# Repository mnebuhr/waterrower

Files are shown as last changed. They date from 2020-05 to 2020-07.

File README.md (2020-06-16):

# waterrower 
connect waterrower to a new Interface

Der Waterrower soll ein neues Interface bekommen. Es sollen live Daten ermittelt werden und diese auf einer grafischen interaktiven Oberfläche dargestellt werden. 

### Stand 06.06.2020 (Canvas)
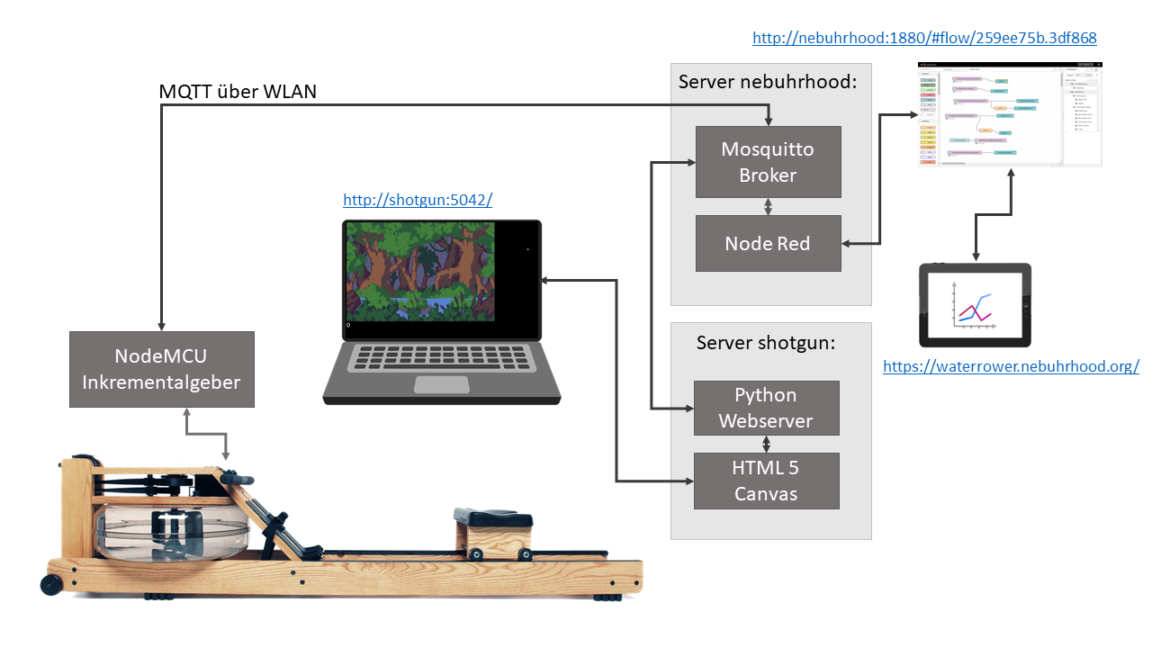
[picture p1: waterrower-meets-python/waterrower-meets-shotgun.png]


### Zwischenstand 26.05.2020 (ohne Gyrosensor)
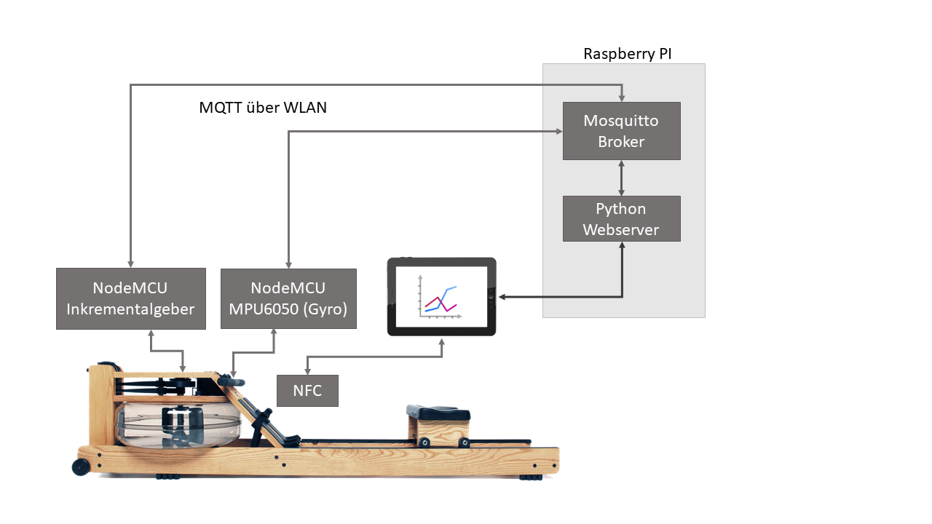
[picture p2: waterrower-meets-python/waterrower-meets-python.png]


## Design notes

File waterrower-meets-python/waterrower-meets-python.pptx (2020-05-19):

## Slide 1

Raspberry PI

Mosquitto
Broker

Python
Webserver

MQTT über WLAN

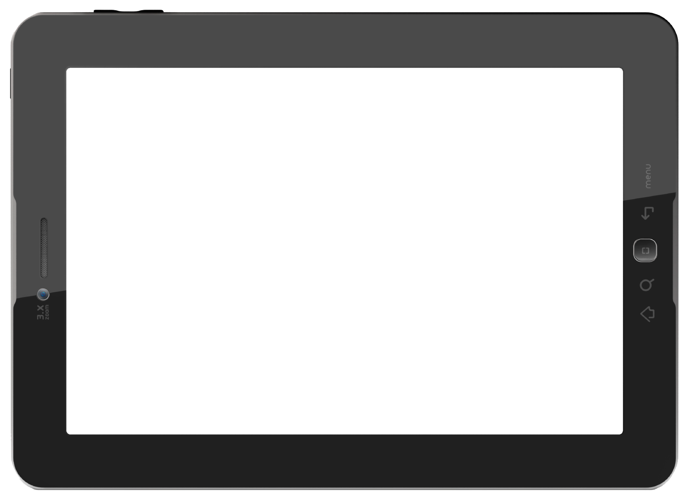
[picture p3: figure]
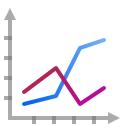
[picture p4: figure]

NodeMCU
Inkrementalgeber

NodeMCU
MPU6050 (Gyro)

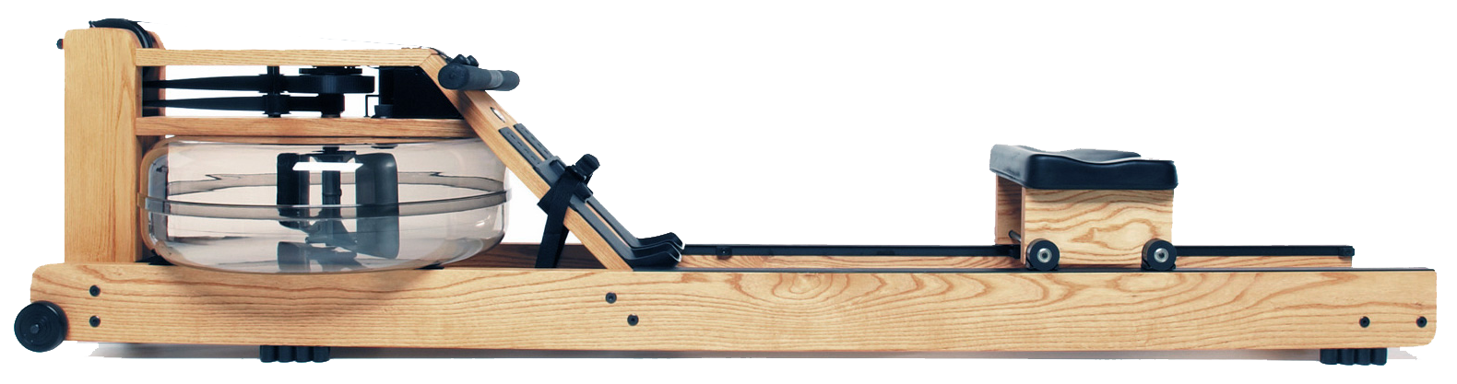
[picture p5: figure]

NFC

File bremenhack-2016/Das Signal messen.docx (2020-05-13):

# Das Signal messen

Zu Beginn muss untersucht werden, welches Signal der Waterrower ausgibt?

Der Waterrower besitzt einen Magnetschalter, bestehend aus einem Sensor und 6 Magneten, die auf einer Scheibe im Kreis angeordnet sind. Dreht sich das Wasserrad bewegen sich die Magneten am Sensor vorbei. In dem Moment wird der Pin auf Ground gesetzt. Pro Umdrehung wird der Pin 6 x auf Ground gesetzt.

Für die Messung des Signals wird der Arduino angeschlossen.

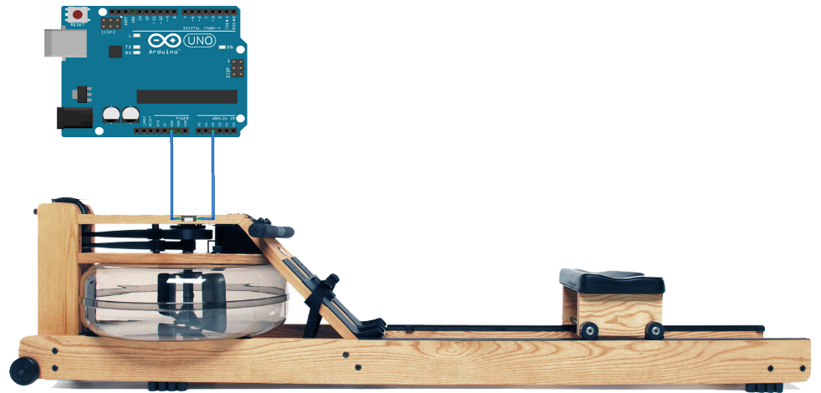
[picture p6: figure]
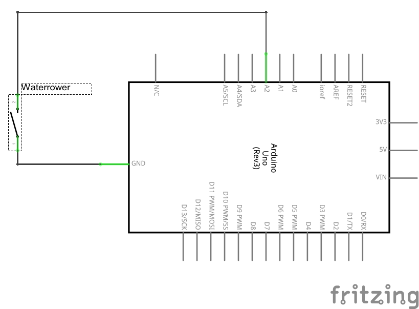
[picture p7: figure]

Bild 1 Für die Messung des Signals wird der Arduino angeschlossen.

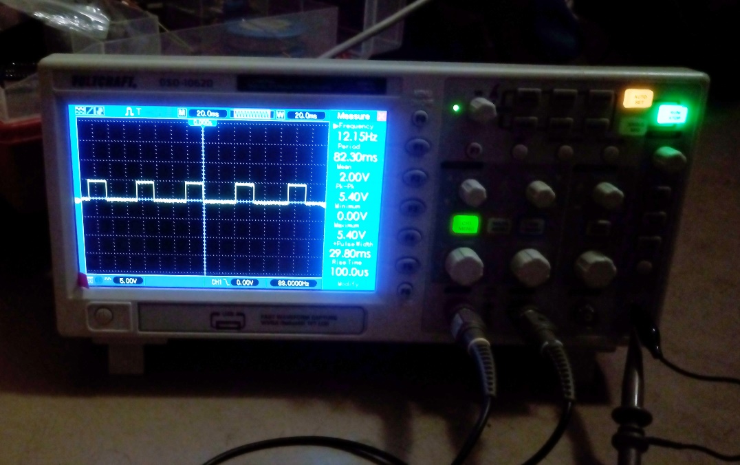
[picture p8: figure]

Bild 2 Das Oszilloskop misst das Signal.

Das Interrupt-Signal ist deutlich erkennbar und kann direkt im Arduino, bzw. später im NodeMSU verarbeitet werden.

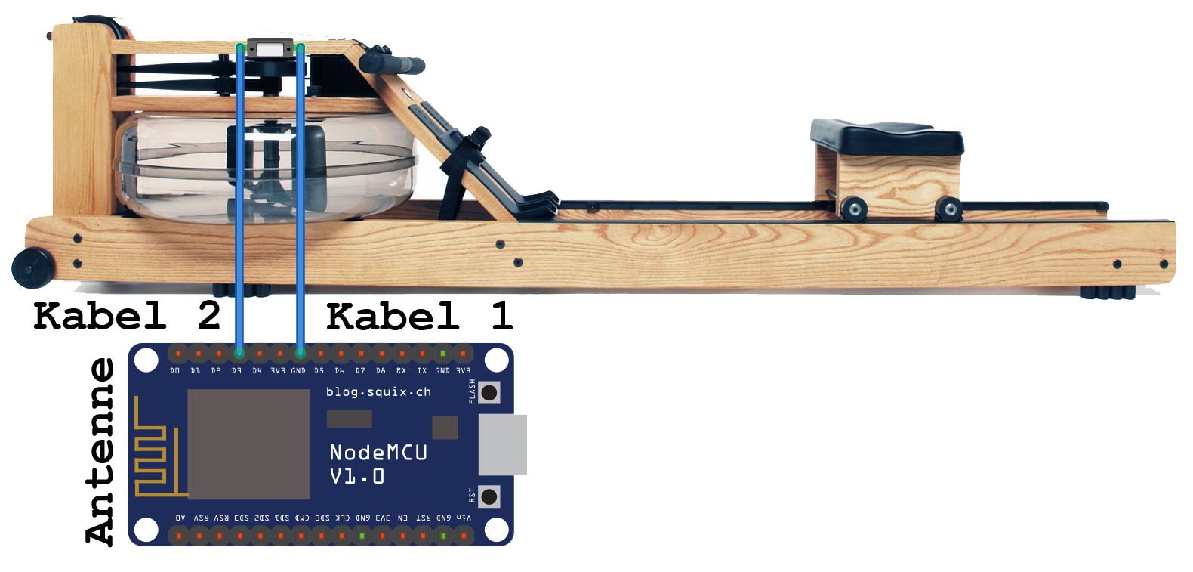
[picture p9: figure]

Bild 3 Waterrower mit NodeMCU Board

# NodeMCU

Der NodeMCU ist ein Komplettbaustein der CPU, RAM, IO-Ports und WiFi vereint. Auf dem Board befindet sich ein ESP8266-Chip für die WLAN Verbindung. Der NodeMCU kann mit der Arduino IDE programmiert werden. Wenn das erste Mal mit dem ESP8266 gearbeitet wird, muss in der Arduino IDE der entsprechende Board Manager in den Voreinstellungen installiert werden. Siehe Anleitung: http://tuxamito.com/wiki/index.php/Arduino_Environment_and_Esp8266

# Berechnung

Das Signal wird vom NodeMSU entgegengenommen.

const int ROWER_PIN = 4;

Der NodeMCU Sketch berechnet aus dem Signal die folgenden Werte:

- Anzahl der Tics
- Dauer
- Entfernung
- Geschwindigkeit.

Die Variablen zur Berechnung der Anzahl der Tics werden als Voltaile Variablen deklariert.

volatile unsigned long tick = 0;

volatile unsigned long lasttick = 0;

volatile float meter_per_second = 0.0;

volatile unsigned long seconds = 0;

Um die zurückgelegte Entfernung zu berechnen wird eine Konstante festgelegt. Basierend auf den Bitbucket Repository Eintrag von Giordano Bianchi (https://bitbucket.org/giobianchi/yun_rower) wurde die Konstante auf 4.805 festgelegt. Das bedeutet, der Sensor hat 4.805 Tics entgegengenommen.

const float ratio = 4.805;

Die Daten werden anschließend an den Raspberry Pi gesendet.

## Raspberry Pi

Auf dem Raspi ist MQTT Booker von Mosquito installiert.

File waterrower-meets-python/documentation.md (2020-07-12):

# Dokumentation

Waterrower System (16.06.2020)
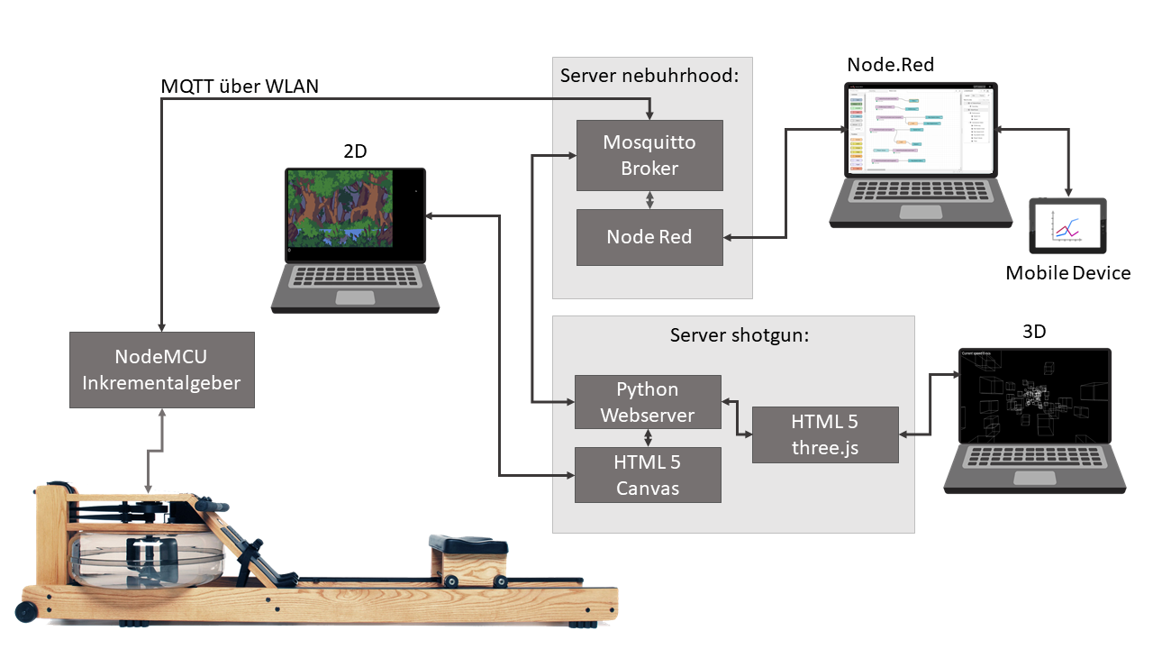
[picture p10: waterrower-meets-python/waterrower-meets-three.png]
waterrower system


## Videos: 
https://drive.google.com/file/d/11Y4omaRP-BRkYAcbQQviKOUNP_x2pU_6/view?usp=sharing
https://drive.google.com/file/d/1YEi5VG4MpYDuGJVBlnGvpaoNKF_MHK11/view?usp=sharing

## Firmware broadcast functions
Arduino Code auf dem Node MCU
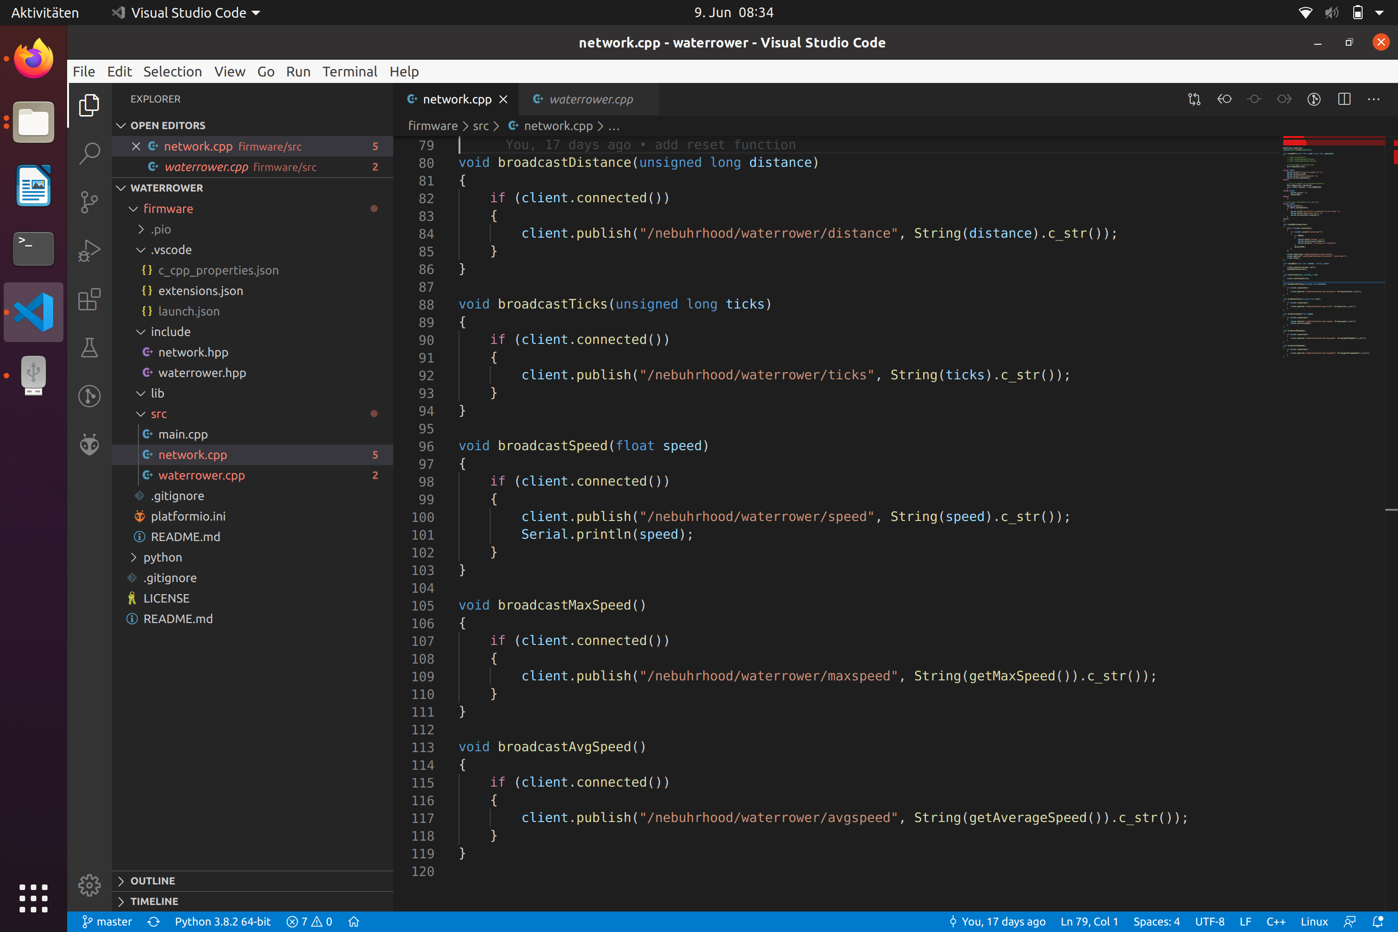
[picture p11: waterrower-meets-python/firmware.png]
firmware


Die folgenden Values werden übertragen

- ticks
- speed
- maxspeed
- avgspeed

## Halterung mit 3D-Druck
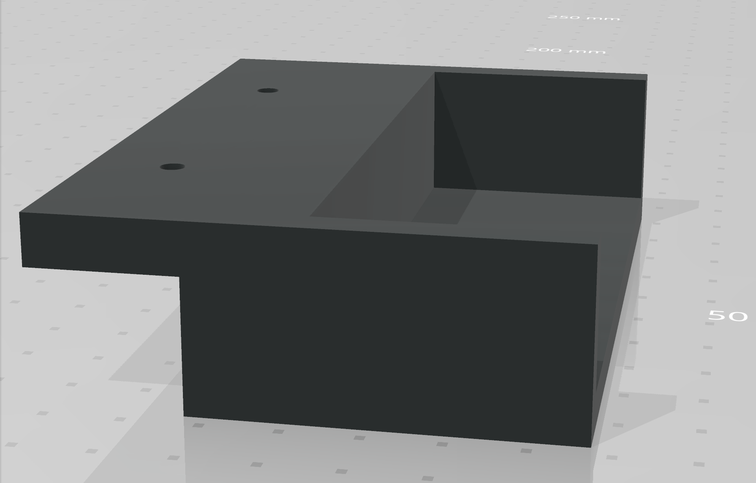
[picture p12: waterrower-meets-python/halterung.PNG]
Halterung


3D Object - STL

## Konfiguration in Node-Red

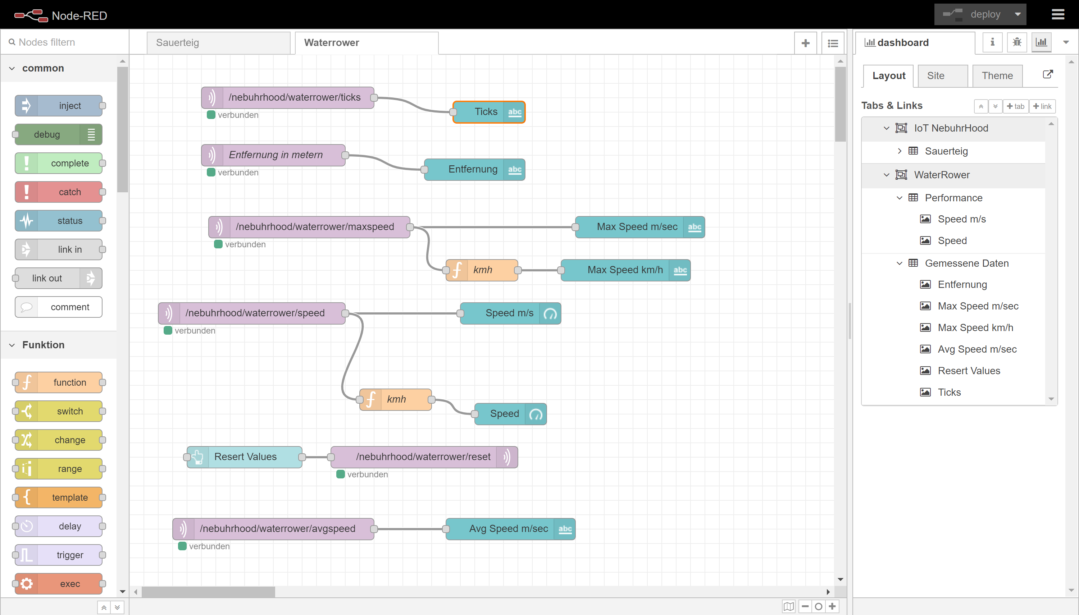
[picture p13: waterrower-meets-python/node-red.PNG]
node-red


## Node-Red Display
https://waterrower.nebuhrhood.org/#!/0?socketid=Sc35ifwYYR3e4bGFAAMr

## Programmierung PyServer
Tutorial: https://responder.kennethreitz.org/en/latest/

```python
import json
import responder
import asyncio
from asyncio_mqtt import Client
from starlette.websockets import WebSocketDisconnect

api = responder.API(static_dir="static")

waterrower_speed = 0.0

@api.route("/")
async def greet_world(req, resp):
    resp.html = api.template('hello.jinja')

async def handle_message(client, data):
    async with client.filtered_messages("/nebuhrhood/waterrower/speed") as messages:
    #async with client.unfiltered_messages() as messages:
        async for message in messages:
            waterrower_speed = float(message.payload)
            data["waterrower_speed"] = waterrower_speed

@api.route('/ws', websocket=True)
async def websocket(ws):

    loop = asyncio.get_event_loop()
    await ws.accept()
    connected = True
    counter = 0
    async with Client("nebuhrhood") as client:
        await client.subscribe("/nebuhrhood/waterrower/#")
        data = {}
        data["waterrower_speed"] = 12
        task = loop.create_task(handle_message(client, data))
        while connected:
            try:
                name = await ws.receive_text()
                
                await ws.send_text(f"{data['waterrower_speed']}")
                counter = counter + 1
            except WebSocketDisconnect:
                connected = False
                task.cancel()
    await ws.close()

if __name__ == '__main__':
    api.serve(address="0.0.0.0")
    # asyncio.run(main())
```
## Programmierung HTML mit Canvas und JavaScript

Thanx to https://craftpix.net/freebies/free-swamp-game-tileset-pixel-art/ for the graphics.
Zunächst die Animation in 2D, bzw. 2 1/2 D mit fertigen Grafiken. Die nächste Herausforderung ist, die Animation in 3D darzustellen.  
 
```html
<!DOCTYPE html>
<html>

<head>
    <meta http-equiv="Content-Type" content="text/html; charset=utf-8"/>
    <script type="application/javascript">

        var background = new Image();
        var layer = [
            {
                image : new Image(),
                x : 0,
                y : 0,
                factor : 0.5
            }, 
            {
                image : new Image(),
                x : 0,
                y : 0,
                factor : 1,
            }, 
            {
                image : new Image(),
                x : 0,
                y : 0,
                factor : 2.0,
            }, 
            {
                image : new Image(),
                x : 0,
                y : 0,
                factor : 4.0
            } 
        ] 

        layer[0].image.src = '/static/image/2.png';
        layer[1].image.src = '/static/image/3.png';
        layer[2].image.src = '/static/image/4.png';
        layer[3].image.src = '/static/image/5.png';

        var x = 0;
        var dx = 0;
        var speed = 0;
        const width = 576*2;
        const height = 423*2;
        var speed_elem = null;

        const mysocket = new WebSocket("ws://192.168.178.62:5042/ws");
        mysocket.onopen = function (event) {
            mysocket.send("get_speed");
        };

        mysocket.onmessage = function(event) {
            //data = JSON.parse(event.data);
            speed = parseFloat(event.data);
            dx = -2 * speed;
            //console.log(event.data);
        };

        mysocket.onclose = function(event) {
            console.log("Socket closed");
        }
        
        background.src = '/static/image/1.png';
        background.onload = function() {
            console.log("image loaded")
        }
        
        function updateData() {
            if (mysocket.readyState != WebSocket.OPEN) {
                console.error("webSocket is not open: " + mysocket.readyState);
            } else {
                mysocket.send("get_speed");
            }
        }

        function play() {
            setInterval(draw, 30);
            setInterval(updateData, 500);
            speed_elem = document.getElementById("wr_speed");

        }

        function drawLayer(ctx, idx) {
            l = layer[idx]
            ctx.drawImage(l.image, l.x+width, 0,width, height);
            ctx.drawImage(l.image, l.x, 0,width, height);
            l.x += (dx * l.factor);
            if (l.x < -width) {
                l.x += width;
            }            
        }
        function draw() {
            console.log(speed);
            speed_elem.textContent = speed;
            var canvas = document.getElementById("canvas");
            if (canvas.getContext) {
                var ctx = canvas.getContext("2d");
                ctx.drawImage(background,0,0,width, height);
                drawLayer(ctx, 0);
                drawLayer(ctx, 1);
                drawLayer(ctx, 2);
                drawLayer(ctx, 3);
            }
        }
    </script>
</head>

<body onload="play();" style="background-color:black;vertical-align:center;">
    <canvas id="canvas" width="1152" height="846"></canvas>
    <div id="wr_speed" style="font-size:3em; color:white; font-family: Roboto, Helvetica, Arial">SPEED</div>
</body>

</html>   
```
## Programmierung HTML mit THREE und JavaScript 
```html
<!DOCTYPE html>
<html>

<head>
    <meta charset="utf-8">
    <title>My first three.js app</title>
    <style>
        body {
            margin: 0;
        }

        canvas {
            display: block;
        }
    </style>
</head>

<body>
    <script src="js/three.js"></script>
    <script>
        var boxes = [];
        var maxDepth = 5.5;
        var numberOfBoxes = 100;
        var boxSize = 0.5;
        var speedFactor = 1.0;
        var globalSpeed = 0.1;
        var maxDeviationX = 3;
        var maxDeviationY = 2;
        var originZ = 18;

        // the max. positiv position on the z axis,
        // bevor the box gets reset.
        var maxDepth = 5.5; 

        function createBox() {

            var geometry = new THREE.BoxGeometry(boxSize, boxSize, boxSize);
            var edges = new THREE.EdgesGeometry( geometry );
            var line = new THREE.LineSegments( edges, new THREE.LineBasicMaterial( { color: 0xffffff } ) );

            return {
                geometry: geometry,
                edges: edges,
                line: line,
                depth: 0.0,
                speedFactor: 1.0,
                move: function(delta) {
                    var dz = delta * this.speedFactor;
                    this.depth += dz;
                    line.geometry.translate(0,0,dz);
                },
                checkDepth: function(d) {
                    if (this.depth > d) {
                        this.move(-1 * (d+18));
                    };
                }
            }
            
        };

        /**
        * Creates a box with randomized position.
        */
        function createRandomizedBox() {
            var box = createBox();
            var randX = (Math.random() * (maxDeviationX*2)) - maxDeviationX;
            var randY = (Math.random() * (maxDeviationY*2)) - maxDeviationY;
            var randZ = (Math.random() * (originZ + maxDepth)) - originZ;
            //var randZ = (Math.random() * (23)) - 18;
            box.speedFactor = Math.random() + 0.5;
            box.line.geometry.translate(randX, randY, 0);
            box.move(randZ);
            return box;
        }

        var scene = new THREE.Scene();
        var camera = new THREE.PerspectiveCamera( 75, window.innerWidth / window.innerHeight, 0.1, 1000 );
        var lines = [];

        var renderer = new THREE.WebGLRenderer();
        renderer.setSize( window.innerWidth, window.innerHeight );
        document.body.appendChild( renderer.domElement );

        // Create som random boxes and store them in an array.
        for (i=0; i<numberOfBoxes; i++) {
            boxes.push(createRandomizedBox());
        };

        // Add the boxes to the scene
        for (box of boxes) {
            scene.add( box.line );
        };
        
        camera.position.z = 5;

        var animate = function () {
            //box.line.geometry.translate(0,0,0.1);
            for (box of boxes) {
                box.move(globalSpeed);
                box.checkDepth(maxDepth);
            };
            requestAnimationFrame( animate );
            renderer.render( scene, camera );
        };

        animate();
    </script>
</body>

</html>
```

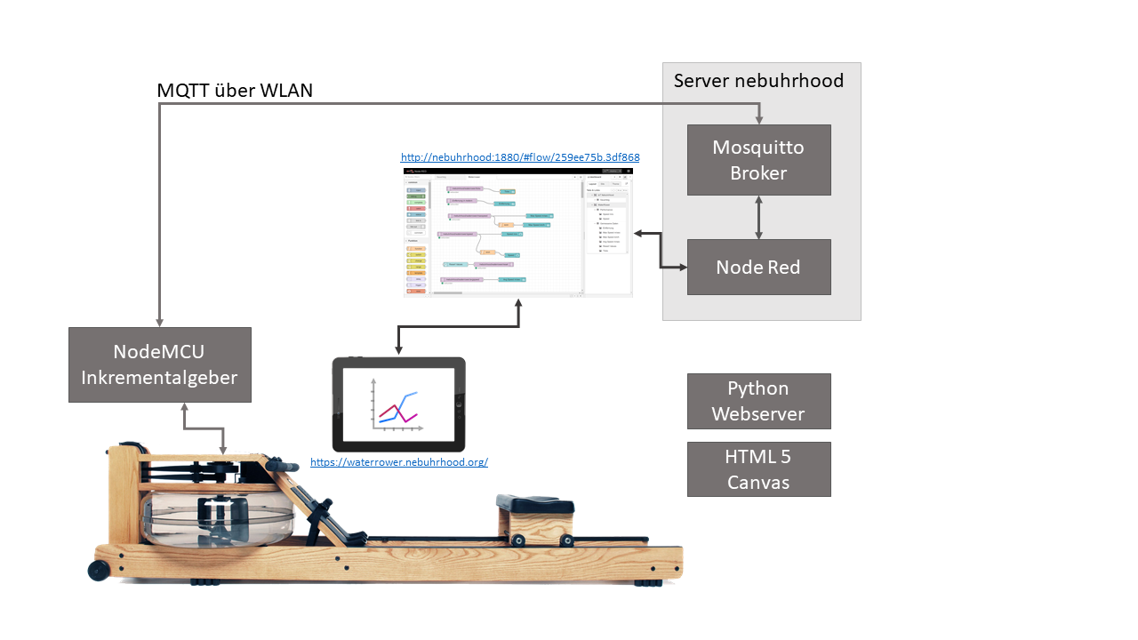
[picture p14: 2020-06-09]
waterrower-meets-python/waterrower-meets-node-red.png

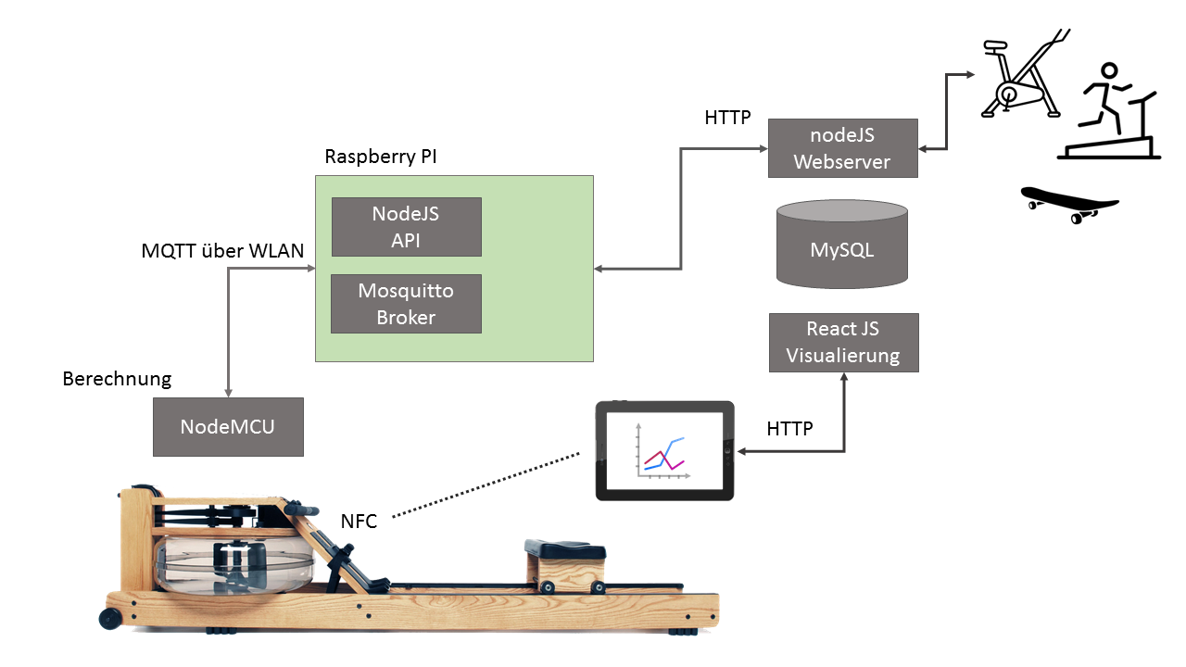
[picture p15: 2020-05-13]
bremenhack-2016/sportshub.png

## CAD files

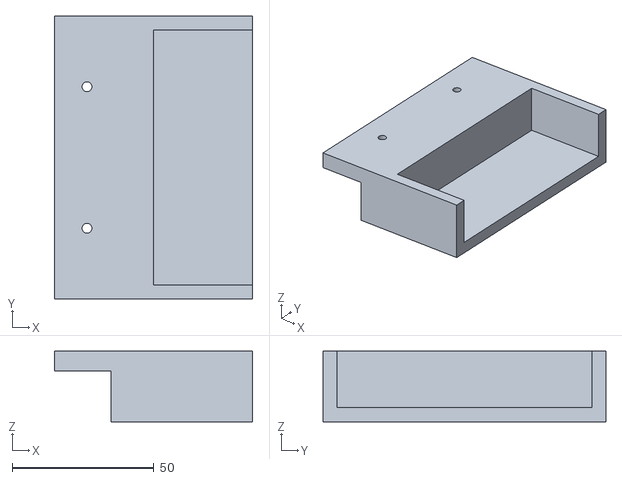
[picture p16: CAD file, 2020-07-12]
waterrower-meets-python/Handyhalter.stl
70.0 x 100.0 x 25.0

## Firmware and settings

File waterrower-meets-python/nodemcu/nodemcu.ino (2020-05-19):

/*
 Project WaterRower meets Pythonein

 @author: Marion Nebuhr
 @created: 2020-05-15
 
*/
#include "commands.h"
#include "waterrower.h"


const byte PIN_MODE_WRITE = 1;
const byte PIN_MODE_READ  = 0;

const byte PIN_STATE_HIGH = 1;
const byte PIN_STATE_LOW  = 0;

#define DEBUG

void setup()
{   
  pinMode(LED_BUILTIN, OUTPUT);
  // Setup console
  Serial.begin(9600);
  delay(10);
  
  pinMode(ROWER_PIN, INPUT_PULLUP);
  digitalWrite(ROWER_PIN,HIGH);

  Serial.println("Start measuring");
  startMeasuring();
  startClock();
}


void loop()
{
  delay(1000);
  Serial.println(getDistanceInMeter());
}
